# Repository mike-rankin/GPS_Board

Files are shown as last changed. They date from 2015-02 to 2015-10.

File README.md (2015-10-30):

On a Windows 7 machine place the contents on libraries.zip into a temp file on your computer.
Install Arduino 1.0.6

Place the TinyGPS library in your Arduino/libraries folder. On my PC its  MyDocuments/Arduino/libraries
Place the PinChangeInt library in your Arduino/libraries folder. On my PC its  MyDocuments/Arduino/libraries

In the same place as where the GPS_Cube.ino sketch is, place data.h, EEPROMAnything.h, mySoftwareSerial.cpp and mySoftwareSerial.h all in the same foilder.

Plug in the GPS Board and hopefully the FTDI chip driver will auto install, a new com port will appear
Pick Tools,Board Arduino Pro or Pro Mini
Pick Tools, Processor, ATmega328 (3.3v, 8 Mhz)
Verify in the IDE by viewing in Tools, Port does indeed show the new com port

Then in the IDE open the GPS_Cube.ino file. If it compiles error free then you are good to upload the sketch.

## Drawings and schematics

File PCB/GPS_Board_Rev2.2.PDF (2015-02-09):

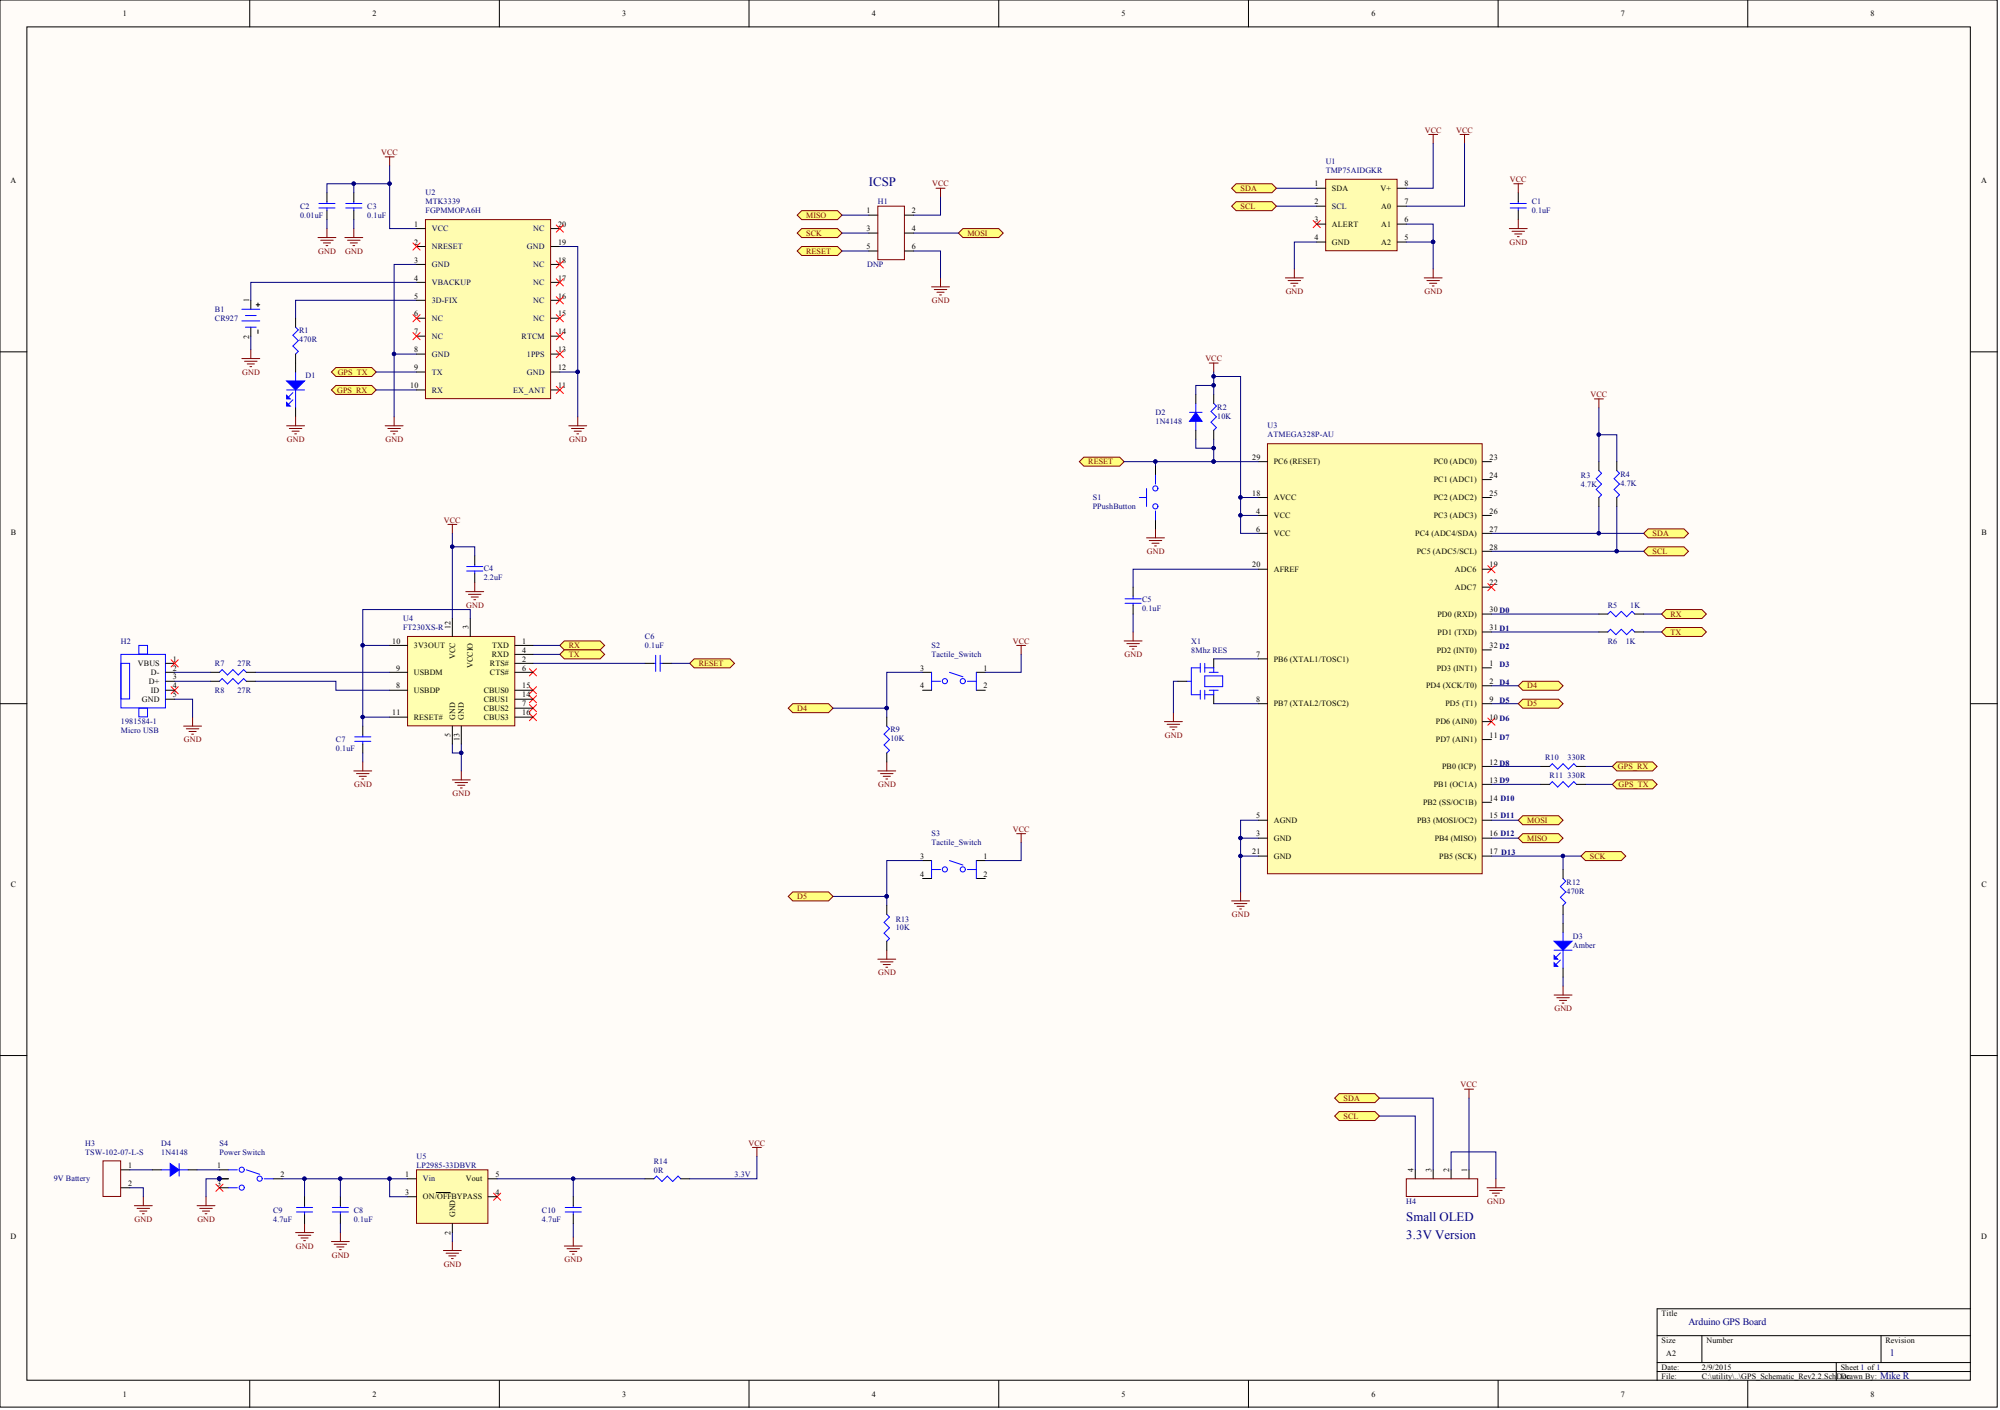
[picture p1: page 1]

VBACKUP 4

3D-FIX 5

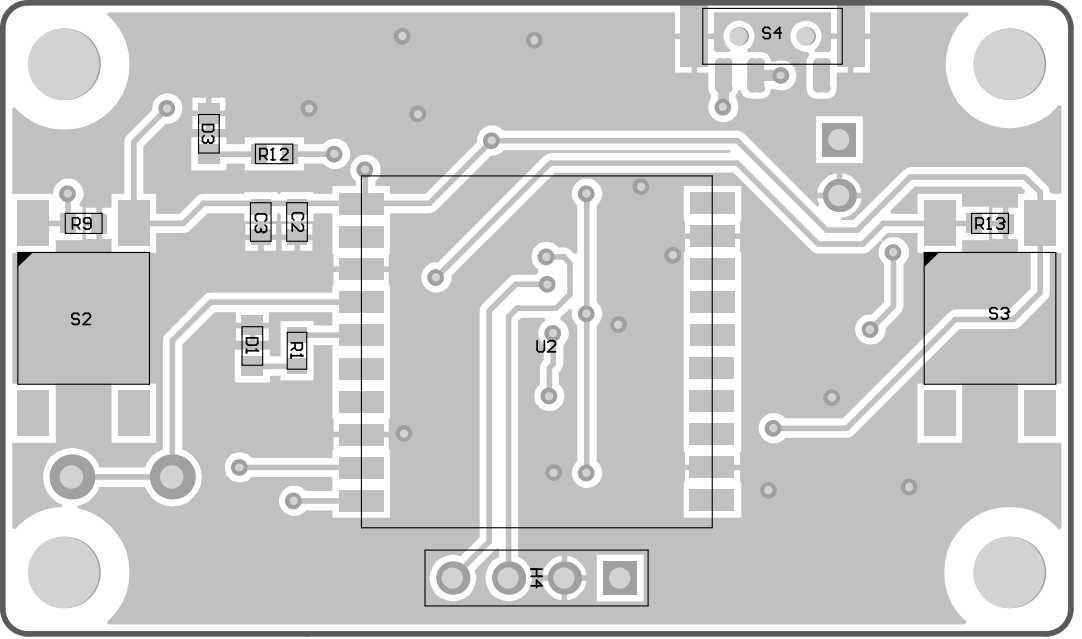
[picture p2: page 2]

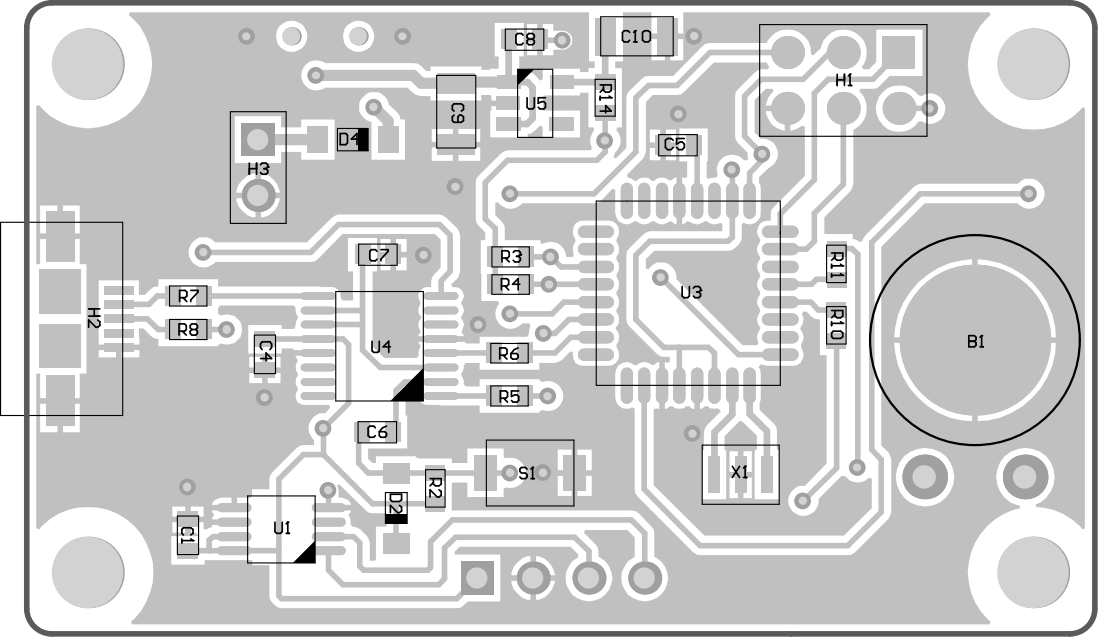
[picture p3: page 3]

Component list | Bill of Materials For Project [GPS_Board.PrjPCB] (No PCB Document Selected)
Source Data From: | GPS_Board.PrjPCB
Project: | GPS_Board.PrjPCB
Report Date: | 2/9/2015 | 10:23:58 AM
Print Date: | 09-Feb-15 | 10:24:01 AM

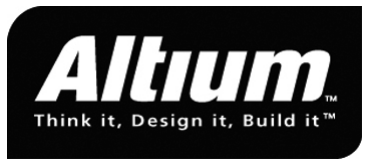
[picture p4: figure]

# | Designator | Quantity | Vendor | PartNumber | Description | Manufacturer | Comment

1 | B1 | 1 | DX.com | 202984 | Custom CR927 mount | | CR927
2 | C1, C3, C5, C6, C8 | 5 | | | CAP CER 0.1uF, 0603
3 | C2 | 1 | | | CAP CER 0.01uF, 0603 | | 0.01uF
4 | C4 | 1 | | | 2.2uF, 0602 | | 2.2uF
5 | C7 | 1 | | | CAP CER 0.1uF, 0603 | | 0.1uF
6 | C9, C10 | 2 | | | CAP CER 4.7uF, 1206 | | CAP_1206
7 | D1 | 1 | | | LED_0603 | | Green LED
8 | D2, D4 | 2 | Digikey | 1N4148W-TP | DIODE SWITCH 100V 0.15A SOD123 | Micro Commercial | 1N4148
9 | D3 | 1 | | Amber | LED_0603 | | LED_0603
10 | H1 | 1 | | DNP | CONN HEADER 3X2POS .100" PADS | | DNP
11 | H2 | 1 | Digi-Key | 1981584-1 | CONN RCPT MICRO USB TYPE AB | TE Connectivity | Micro USB
12 | H3 | 1 | | | CONN HEADER 2POS .100" SGL GOLD | Samtec | TSW-102-07-L-S
13 | H4 | 1 | | | CONN HEADER 4POS .100" SGL GOLD | Samtec | TSW-104-07-L-S
14 | R1, R12 | 2 | | | RES 0603 | | 470R
15 | R2, R9, R13 | 3 | | | RES 0603 | | 10K
16 | R3, R4 | 2 | | | RES 0603 | | 4.7K
17 | R5, R6 | 2 | | | RES 0603 | | 1K
18 | R7, R8 | 2 | | | RES 0603 | | 27R
19 | R10, R11 | 2 | | | RES 0603 | | 330R
20 | R14 | 1 | | | RES 0603 | | 0R
21 | S1 | 1 | | 122514 | DX_SWITCH TACTILE | | PPushButton
22 | S2, S3 | 2 | Digikey | FSM6JSMA | SWITCH TACTILE SPST-NO 0.05A 12V | TE Connectivity | Tactile_Sw itch
23 | S4 | 1 | DX.com | 122531 | DX_SWITCH SLIDE SPDT R/A
24 | U1 | 1 | Digikey | TMP75AIDGKR | IC DGTL TEMP SENSOR 2WIRE 8-MSOP | Maxim | TMP75AIDGKR
25 | U2 | 1 | | FGPMMOPA6H | GPS Chip - FGPMMOPA6H | Global Top | MTK3339
26 | U3 | 1 | Digikey | ATMEGA328P-AU | MCU AVR 32K FLASH 32TQFP | Atmel | ATMEGA328P-AU
27 | U4 | 1 | Digikey | FT230XS-R | IC USB SERIAL BASIC UART 16SSOP | FTDI | FT230XS-R
28 | U5 | 1 | Digikey | LP2985-33DBVR | IC REG LDO 3.3V .15A SOT23-5 | Texas Instruments | LP2985-33DBVR
29 | X1 | 1 | Digikey | CSTCE8M00G55-R0 | CER RESONATOR 8.0MHZ SMD | Murata
Approved | Notes

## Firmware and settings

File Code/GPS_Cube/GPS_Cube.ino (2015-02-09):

//Modified print_coord(); to prevent locking up in certain countries

//==========================================================//
//                                                          //
//    GPS Toy By KaR]V[aN, http://karman.homelinux.net      //
//    Thanks to the Arduino comunity for providing code,    //
//    libraries and platforms. Also many thanks to Nitz,    //
//    whose coding skills helped so much.                   //
//                                                          //
//==========================================================//

/* 
 * This is a simple GPS Toy/'on board computer' that shows GPS
 * data in a tiny 128x64 OLED display (I2C driven, 0.96").
 * Because being I2C display the frame rate is very slow 
 * but saves pins for future use.
 */
 
#include <EEPROM.h>
#include "EEPROMAnything.h"
#include "mySoftwareSerial.h" 
#include <TinyGPS.h>
#include <Wire.h>
#include <avr/pgmspace.h>

// So, why use a custom software serial? This addresses a problem sharing 
// interrupts between pinchangeint and software serial, by disabling the 
// unsued ports on both of them. Meanwhile pinchangeint allows easy disabling,
// newsoftwareserial doesn't, so have to comment code. More info:
// http://code.google.com/p/arduino-pinchangeint/issues/detail?id=7

//---------------FONT + GRAPHIC-----------------------------//
#include "data.h"
//==========================================================//

// OLED I2C bus address
#define OLED_address  0x3c

// Setup the GPS MT3339 receiver
#define PMTK_SET_NMEA_OUTPUT_RMCGGA "$PMTK314,0,1,0,1,0,0,0,0,0,0,0,0,0,0,0,0,0,0,0*28\r\n" // turn on GPRMC and GPGGA —– TinyGPS only uses these two, all others can be turned off
#define PMTK_SET_NMEA_UPDATE_1HZ "$PMTK220,1000*1F\r\n" // Every 1000ms (1Hz)
#define PMTK_SET_NMEA_UPDATE_2HZ "$PMTK220,500*2B\r\n" // Every 500ms (2Hz)
#define PMTK_SET_NMEA_BAUDRATE "$PMTK251,4800*14\r\n" // Baudrate to 4800
#define PMTK_API_SET_SBAS_ENABLED "$PMTK313,1*2E"   // Enable SBAS sattelite for fast fix
#define PMTK_API_SET_SBAS_Mode "$PMTK319,1*24"      // Integrity mode

// I'll attach interrupt to digital pins 4 and 5, both 
// on port D. Both ports B and C are to be disabled:
#define NO_PORTB_PINCHANGES // to indicate that port b will not be used for pin change interrupts
#define NO_PORTC_PINCHANGES // to indicate that port c will not be used for pin change interrupts
#include <PinChangeInt.h>

TinyGPS gps;
SoftwareSerial nss(9, 8);
static bool feedgps();
const int buttonA = 4;
const int buttonB = 5;
unsigned int buttonStateB = 0;      
unsigned int buttonStateA = 0;       
unsigned int mode=0;
bool course_degree = false;
bool control_blink = false;
bool control_clock = false;
bool interrupt = false;
bool doing_menu = false;
float SAVED_LAT = 0.0, SAVED_LON = 0.0, LAST_LAT = 0.0, LAST_LON = 0.0;
unsigned int TZ = 2;
unsigned long int tripDistance = 0;
static const byte settings_version = B10000011;
bool fix_first = 1;
float last_course = 0.0;
int TMP75_Address = 0x49;
float miniTimer = millis();
bool debug = 0; // turns on GPS data over USB serial



//---------------Saved Data Map-----------------------------//
// Bytes  Size  Purpose
// ····························································
// 0      1     Settings Version
// 1-4    4     Saved Latitude
// 5-8    4     Saved Longitude
// 9-10   2     Saved Mode
// 11     1     Saved Course preference (Degrees - Cardinal)
// 12     1     Saved Clock prefence (12h - 24h)
// 13-14  2     Saved Time Zone
// 15-18  4     Saved trip distance
//==========================================================//


void setup()
{
  // Load previous Settings
  byte read_settings_version;
  EEPROM_readAnything(0, read_settings_version);
 
  if(settings_version == read_settings_version) // If version matchs, load vars from EEPROM
  {  
    EEPROM_readAnything(1, SAVED_LAT);
    EEPROM_readAnything(5, SAVED_LON);
    EEPROM_readAnything(9, mode);
    EEPROM_readAnything(11, course_degree);
    EEPROM_readAnything(12, control_clock);
    EEPROM_readAnything(13, TZ);
    EEPROM_readAnything(15, tripDistance);
  }
  else                                          // If not, initialize with defaults
  {
    EEPROM_writeAnything(0, settings_version);
    EEPROM_writeAnything(1, SAVED_LAT);
    EEPROM_writeAnything(5, SAVED_LON);
    EEPROM_writeAnything(9, mode);
    EEPROM_writeAnything(11, course_degree);
    EEPROM_writeAnything(12, control_clock);
    EEPROM_writeAnything(13, TZ);
    EEPROM_writeAnything(15, tripDistance);
  }
  
  // Buttons...
  pinMode(buttonA, INPUT);
  pinMode(buttonB, INPUT);    
  digitalWrite(buttonA, LOW);
  digitalWrite(buttonB, LOW);
  
  // Attach interrupts to both buttons on rising change
  PCintPort::attachInterrupt(buttonA, &interrupt_button, RISING); 
  PCintPort::attachInterrupt(buttonB, &interrupt_button, RISING); 
 
  // Initialize GPS receiver
  // nss.begin(4800); // Old GPS EM411
  // Init in 9600 just in case MT3339 lost its settings
  nss.begin(9600);
  while (!nss.available()){} // yeah I know, ugly way to empty buffer...
  nss.print(PMTK_SET_NMEA_BAUDRATE); // baudrate to 4800

  // .. then delay 10ms and re-initialize in 4800
  delay(10);  
  nss.begin(4800);   
  while (!nss.available()){} // ...
  nss.print(PMTK_SET_NMEA_OUTPUT_RMCGGA); // $GPxxx Messages
  nss.print(PMTK_SET_NMEA_UPDATE_1HZ); // messages 2 times a second
  nss.print(PMTK_API_SET_SBAS_ENABLED); // enable SBAS fixing
  nss.print(PMTK_API_SET_SBAS_Mode); // integrity mode for SBAS
 
  // Initialize I2C and OLED Display
  Wire.begin();
  init_OLED();
 
  // Initialize TMP75
  Wire.beginTransmission(TMP75_Address);       // Address the TMP75 sensor
  Wire.write(0x01);                       // Address the Configuration register 
  Wire.write(B01100000);                         // Set the temperature resolution 
  Wire.endTransmission();                      // Stop transmitting
  Wire.beginTransmission(TMP75_Address);       // Address the TMP75 sensor
  Wire.write(0x00);                          // Address the Temperature register 
  Wire.endTransmission();                      // Stop transmitting 

  reset_display();           // Clear logo and load saved mode
  nss.listen();
  if (debug)
    Serial.begin(115200);
}


//==========================================================//
void loop()
{  
  // Read Button state
  if (buttonStateA == HIGH || buttonStateB == HIGH)
  {
    doing_menu = true;                            // we are in button fuctions, ignore interrupt bool
    unsigned long button_delay = millis();
    
    while (millis() - button_delay < 50) 
    {
      if (buttonStateA == LOW) 
        buttonStateA = digitalRead(buttonA);
      if (buttonStateB == LOW) 
        buttonStateB = digitalRead(buttonB);
    }
      
    // Both buttons pushed
    if (buttonStateB == HIGH && buttonStateA == HIGH)
    {
      displayOff();
      setXY(0,0);
  
      for(int i=0;i<128*8;i++)     // show 128* 64 Logo
        SendChar(pgm_read_byte(logo+i));
    
      displayOn();
      sendStrXY("Carlos Sancho",7,2);
      sendStrXY("v1.1", 0, 12);
      delay(5000);
      clear_display();
      sendStrXY("Hardware Design by Mike Rankin",0,0);
      sendStrXY("Using TinyGPS by Mikal Hart",3,0);
      sendStrXY("http://karman.cc",6,0);
      delay(5000);
      reset_display();
    }
    
    // Menu/mode button
    else if(buttonStateA == HIGH && buttonStateB == LOW) 
    {
      // Change mode
      if (mode == 0) 
        mode = 1;
      
      else if (mode == 1) 
        mode = 2;
        
      else if (mode == 2)
        mode = 3;
        
      else if (mode == 3)
        mode = 0;
      
      EEPROM_writeAnything(9, mode); // Save mode
      reset_display();
    } 
    
    // Other button
    else if (buttonStateB == HIGH && buttonStateA == LOW) 
    {
      reset_buttons();
      
      // Change cardinal <-> degrees
      if (mode == 0) 
      {
        course_degree = !course_degree;
        EEPROM_writeAnything(11, course_degree);
        reset_display();
      }
      
      // Memorize current location after 3 seconds pushing button
      else if (mode == 1) 
      {
        displayOff();
        clear_display();
        sendStrXY("Memorizing in: ", 0, 0);
        printBigNumber('3', 3 ,6);
        displayOn();
        boolean exit = 0;
        unsigned long start = millis();
        while (digitalRead(buttonB) == HIGH && !exit)
        {          
          if (millis() - start > 3000) 
          {
            clear_display();
            exit = true;
            sendStrXY("Coordinates memorized:", 0, 0);
            saveActualLoc(gps);
            delay(2000);
          } 
          
          else if (millis() - start > 2000)
            printBigNumber('1', 3 ,6);
            
          else if (millis() - start > 1000)
            printBigNumber('2', 3 ,6);
        }
        reset_display();
      }
      
      // Reset trip 
      else if (mode == 2)
      {
        displayOff();
        clear_display();
        sendStrXY("Clearing in: ", 0, 0);
        printBigNumber('3', 3 ,6);
        displayOn();
        boolean exit = 0;
        unsigned long start = millis();
        while (digitalRead(buttonB) == HIGH && !exit)
        {          
          if (millis() - start > 3000) 
          {
            clear_display();
            exit = true;
            unsigned long age;
            float flat, flon;
            gps.f_get_position(&flat, &flon, &age);
            sendStrXY("Trip reseted", 0, 0);
            tripDistance = 0;
            LAST_LAT = flat;
            LAST_LON = flon;
            EEPROM_writeAnything(15, tripDistance);
            delay(2000);
          } 
          
          else if (millis() - start > 2000)
            printBigNumber('1', 3 ,6);
            
          else if (millis() - start > 1000)
            printBigNumber('2', 3 ,6);
        }
        reset_display();
      }
      
      // Change clock hour mode, 12h <-> 24h in short push (< 3 secs)
      // In long push (> 3 sec) enters in time zone setting mode
      else if (mode == 3)
      {
        reset_buttons();
        boolean exit = 0;
        boolean mode_timezone = false;
        unsigned long start = millis();
        while (digitalRead(buttonB) == HIGH && !exit)
        {
          if (millis() - start > 3000) 
          {
            exit = true;
            mode_timezone = true;
          }
        }
        
        if (mode_timezone)
        {
          displayOff();
          clear_display();
          sendStrXY("Select TimeZone:", 0, 0);
          sendStrXY("Menu to set", 7, 2);
          displayOn();
          reset_buttons();
          bool print_TZ = true;
          while(buttonStateA != HIGH)
          {
            
            if (buttonStateB == HIGH) 
            {
              // this loop avoids false contacts of defective switches and sparks
              while (digitalRead(buttonB) != LOW)
                delay(10); 
              
              buttonStateB = LOW;
              TZ++;
              print_TZ = true;
            }
            
            if (TZ == 13)
              TZ = -11;
            
            // Avoid to print always same value
            if (print_TZ) {
              print_timezone(TZ);
              print_TZ = false;
            }
            
            delay(10); // to not fall into an endless loop. 
          }
          EEPROM_writeAnything(13, TZ);
        }
        else 
        {
          control_clock = !control_clock;
          EEPROM_writeAnything(12, control_clock);
        }
        reset_display();
      }
    }
    reset_buttons();
    doing_menu = false;    // Reset both vars on buttons exit
    interrupt = false;
  }
  
  
  // Update display
  updateScreen(gps);  
     
  // update trip distance
  udpateTrip(gps);
}

// Change button state on interrupt
void interrupt_button (void)
{
  if (PCintPort::arduinoPin == buttonA)
    buttonStateA = HIGH;
  else if (PCintPort::arduinoPin == buttonB)
    buttonStateB = HIGH;
    
  interrupt = true;          // Stop printing on display, speeds up response.
}

// Resets button states
static void reset_buttons(void)
{
  buttonStateA = LOW;
  buttonStateB = LOW;
}

//==========================================================//
// Resets display depending on the actual mode.
static void reset_display(void)
{
  displayOff();
  clear_display();
  if (mode == 0)
  {
    printKmh_unit();
  }
  else if (mode == 1) 
  {
    //nothing here by now
  } 
  else if (mode == 2) 
  {
    sendStrXY("Trip sum:", 0, 3);
  }
  else if (mode == 3)
  {
  //  sendStrXY("Atomic GPS Watch",0,0);
  }  
  updateScreen(gps);
  displayOn();
}

//==========================================================//
// Updates screen depending on the actual mode.
static void updateScreen(TinyGPS &gps) 
{
  unsigned long age;
  float flat, flon;
  gps.f_get_position(&flat, &flon, &age);
  
  if (mode == 0)
  {
    print_date(gps);
    printAlt(gps.f_altitude(), 0, 0);
    printSpeed(gps.f_speed_kmph());
    printSats(gps.satellites(), 0, 10, age);
    printCourse(gps); 
  }  
  else if (mode == 1)
  { 
    print_coord(flat, TinyGPS::GPS_INVALID_F_ANGLE, 0, 0);
    print_coord(flon, TinyGPS::GPS_INVALID_F_ANGLE, 0, 9);
    sendDistanceBetwen(gps);
    printCourse(gps);
    print_coord(SAVED_LAT, TinyGPS::GPS_INVALID_F_ANGLE, 7, 0);
    print_coord(SAVED_LON, TinyGPS::GPS_INVALID_F_ANGLE, 7, 9);
  }
  else if (mode == 2)
  {
    printTrip();
    printTemp(7,0);
    printSats(gps.satellites(), 7, 10, age);
  }
  else if (mode == 3)
  {
    print_date(gps);
    printTemp(0,0);
    printSats(gps.satellites(), 0, 10, age);
  }
}



//==========================================================//
// Shows and saves actual coordinates
static void saveActualLoc(TinyGPS &gps)
{
  unsigned long age;
  float flat, flon;
 
  gps.f_get_position(&flat, &flon, &age);
  sendStrXY("Lat: ", 4, 0);
  sendStrXY("Lon: ", 5, 0);
  print_coord(flat, TinyGPS::GPS_INVALID_F_ANGLE, 4, 5);
  print_coord(flon, TinyGPS::GPS_INVALID_F_ANGLE, 5, 5);
  SAVED_LAT = flat;
  SAVED_LON = flon;
  EEPROM_writeAnything(1, SAVED_LAT);
  EEPROM_writeAnything(5, SAVED_LON);
}

//==========================================================//
// Prints display trip update
static void printTrip () {
 /* char sz[32];
  sprintf(sz, "RAW: %d", tripDistance);
  sendStrXY(sz, 7, 0);*/
  print_distance(tripDistance);
}

//==========================================================//
// Gets current location and if > 20, sums to trip global var.
static void udpateTrip (TinyGPS &gps) {
  unsigned long age;
  float flat, flon;
  int max_dist = 25;
 
  gps.f_get_position(&flat, &flon, &age);
  if (flat == TinyGPS::GPS_INVALID_F_ANGLE)
    return;
  else {
    
    int mySpeed = (int)gps.f_speed_kmph();
    
    if(mySpeed > 5) 
      max_dist = 20;
    if(mySpeed > 10) 
      max_dist = 15;
    if(mySpeed > 15) 
      max_dist = 5;
    
    if(fix_first) 
    {
      LAST_LAT = flat;
      LAST_LON = flon;
      fix_first = false;
      last_course = TinyGPS::course_to(flat, flon, LAST_LAT, LAST_LON);
    } 
    else 
    {
    
      // Distance in meters
      unsigned long int dist = (long int)TinyGPS::distance_between(flat, flon, LAST_LAT, LAST_LON);

      if (dist > max_dist)   
      {
        
        // Try some course correction, props to Nitz
        float actual_course = TinyGPS::course_to(flat, flon, LAST_LAT, LAST_LON);
        float new_course = last_course - actual_course;
        new_course -= new_course / 2;
       
        tripDistance += dist * fabs((float)cos(new_course));
        
        last_course = actual_course;
        LAST_LAT = flat;
        LAST_LON = flon;
        EEPROM_writeAnything(15, tripDistance);
      }
    }   
  }
}

//==========================================================//
// Prints actual course or course to a point (distance mode) 
// in cardinal or dregree mode.
static void printCourse(TinyGPS &gps) 
{
  unsigned long age;
  float flat, flon;
  gps.f_get_position(&flat, &flon, &age);
  
  if (flat == TinyGPS::GPS_INVALID_F_ANGLE) 
    sendStrXY("C:N/A", 2, 10);
  else
  {
    char sz[32];
    if(course_degree)       // Print course in degrees mode
    {
      char sy[10];
      
      if (mode == 0)
        dtostrf(gps.f_course(),3,0,sy);
      else if (mode == 1)
        dtostrf(TinyGPS::course_to(flat, flon, SAVED_LAT, SAVED_LON),3,0,sy);
        
      sprintf(sz, "C:%s", sy);
      
      setXY(2, 15);
      for(int i=0;i<8;i++)     // print degree simbol
        SendChar(pgm_read_byte(myDregree+i));
    }    
    else                // Print course in cardinal mode
    {
      char tmp[3];
     
      if (mode == 0)
        sprintf(tmp, "%s", TinyGPS::cardinal(gps.f_course()));
      else if (mode == 1)
        sprintf(tmp, "%s", TinyGPS::cardinal(TinyGPS::course_to(flat, flon, SAVED_LAT, SAVED_LON)));
        
      int lon = strlen(tmp);
 
      sprintf(sz, "C:% 3s", tmp);
    }
      
    sendStrXY(sz, 2, 10);
  }
}


//==========================================================//
// Prints distance between two points given by actual and saved coordinates.
// To do so, function gets the two mayor magnitudes and prints them.
static void sendDistanceBetwen(TinyGPS &gps) 
{
  unsigned long age;
  float flat, flon;
  //char unit[10] = "m ";
 // char sz[32];
 // char next_unit[2];
 
  gps.f_get_position(&flat, &flon, &age);
  if (flat == TinyGPS::GPS_INVALID_F_ANGLE)
  {
    //sendDistance("000", " m");
    sendSpeed("000");
    sendStrXY("m ", 5, 9);
    sendStrXY("000*", 5, 12);
  }
  else {
    // Distance in meters
    unsigned long int dist = (long int)TinyGPS::distance_between(flat, flon, SAVED_LAT, SAVED_LON);
    print_distance(dist);
 
  }
}

//==========================================================//
// Prints distance.
static void print_distance (unsigned long int dist)
{
   char unit[10] = "m ";
   char sz[32];
   char next_unit[2];
   char tmp[32];
   unsigned long int little_ones;
   unsigned long int big_ones;
   
   if (dist >= 1000000000) 
    {
      little_ones = (dist % 1000000000) / 1000000;
      big_ones = (dist - (little_ones * 1000000)) / 1000000000;
      sprintf(next_unit, "%s", "M");
      sprintf(unit, "%s", "Gm");
    }
    else if (dist >= 1000000) 
    {
      little_ones = (dist % 1000000) / 1000;
      big_ones = (dist - (little_ones * 1000)) / 1000000;
      sprintf(next_unit, "%s", "K");
      sprintf(unit, "%s", "Mm");
    }
    else if (dist >= 1000) 
    {
      little_ones = dist % 1000;
      big_ones = ((dist - little_ones) / 1000);
      sprintf(next_unit, "%s", "m");
      sprintf(unit, "%s", "Km");
    }
    else
    {
        big_ones = dist;
        little_ones = 0;
        sprintf(next_unit, "%s", "*");
        sprintf(unit, "%s", "m ");
    }
      
    sprintf(sz, "%03d", big_ones);
      
    sprintf(tmp, "%03d", little_ones);
          
  //  sendDistance(sz, unit);
    sendSpeed(sz);
    sendStrXY(unit, 5, 9);

    sendStrXY(tmp, 5, 12);
    sendStrXY(next_unit, 5, 15);
}


//==========================================================//
// Prints current sattelites being used by GPS module.
static void printSats(int sats, int X, int Y, int age)
{
  if (sats == TinyGPS::GPS_INVALID_SATELLITES || age > 3000)
    sendStrXY("NO SIG", X, Y);
  else {
    char sz[7];
    (sats>9)?sprintf(sz, "%d SAT", sats):sprintf(sz, "0%d SAT", sats);
    sendStrXY(sz, X, Y);
  }
}


//==========================================================//
// Prints altitude adjusting it to display representation.
static void printAlt(float altitud, int X, int Y)
{
  if (altitud == TinyGPS::GPS_INVALID_F_ALTITUDE)
    sendStrXY("00000 m", X, Y);
  else {
    char sz[32];
    int alt = (int)altitud;
    
    if (alt<0)
      sprintf(sz, "-%04d m", abs(alt));
    else
      sprintf(sz, "%05d m", alt);
      
    sendStrXY(sz, X, Y);
  }
}


//==========================================================//
// Prints Speed and it's first decimal adjusting 0 in the left.
static void printSpeed(float val)
{
  if(val == TinyGPS::GPS_INVALID_F_SPEED)
  {
      sendSpeed("000");
      sendStrXY(".0",5,14);
  }
  else {
    char sx[5];
    char sy[5];
    char sz[5];
    int num = (int)val;
    float tmp = val - num;
    
    dtostrf(tmp,3,1,sy);
    sprintf(sx, ".%c", sy[2]);
    sprintf(sz, "%03d", num);
   
    sendSpeed(sz);
    sendStrXY(sx,5,14);
  }
}

//Possibly Locking up Board
/*
//==========================================================//
// Prints a floating coordinate yanking last two decimals for display
// fitting.
static void print_coord(float val, float invalid, int X, int Y)
{
  char sz[] = "*******";
  if (val == invalid)
  {
    sendStrXY(sz,X,Y);
  }
  else
  {
    dtostrf(val,6,4,sz);
    sendStrXY(sz,X,Y);
  }
}
*/


//NEW
static int print_coord(float val, float invalid, int X, int Y)
{
  char sz[20]; //extra headroom since dtostrf size is unclear
  char display[8];
  memset(sz,0,sizeof(sz));
  memset(display,0,sizeof(display));

  if (val == invalid)
  {
    memset(display,'*',sizeof(display)-1);
    sendStrXY(display,X,Y);
  }
  else
  {
    dtostrf(val,6,4,sz);  
    //strncpy does not auto null terminate string 
    //so memset to zero required
    strncpy(display, sz, sizeof(display)-1); 
    sendStrXY(display,X,Y);
  }
  return strlen(display);
}
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

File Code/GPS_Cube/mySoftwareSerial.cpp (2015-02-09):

/*
SoftwareSerial.cpp (formerly NewSoftSerial.cpp) - 
Multi-instance software serial library for Arduino/Wiring
-- Interrupt-driven receive and other improvements by ladyada
   (http://ladyada.net)
-- Tuning, circular buffer, derivation from class Print/Stream,
   multi-instance support, porting to 8MHz processors,
   various optimizations, PROGMEM delay tables, inverse logic and 
   direct port writing by Mikal Hart (http://www.arduiniana.org)
-- Pin change interrupt macros by Paul Stoffregen (http://www.pjrc.com)
-- 20MHz processor support by Garrett Mace (http://www.macetech.com)
-- ATmega1280/2560 support by Brett Hagman (http://www.roguerobotics.com/)

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
The latest version of this library can always be found at
http://arduiniana.org.
*/

// When set, _DEBUG co-opts pins 11 and 13 for debugging with an
// oscilloscope or logic analyzer.  Beware: it also slightly modifies
// the bit times, so don't rely on it too much at high baud rates
#define _DEBUG 0
#define _DEBUG_PIN1 11
#define _DEBUG_PIN2 13
// 
// Includes
// 
#include <avr/interrupt.h>
#include <avr/pgmspace.h>
#include "Arduino.h"
#include "mySoftwareSerial.h"
//
// Lookup table
//
typedef struct _DELAY_TABLE
{
  long baud;
  unsigned short rx_delay_centering;
  unsigned short rx_delay_intrabit;
  unsigned short rx_delay_stopbit;
  unsigned short tx_delay;
} DELAY_TABLE;

#if F_CPU == 16000000

static const DELAY_TABLE PROGMEM table[] = 
{
  //  baud    rxcenter   rxintra    rxstop    tx
  { 115200,   1,         17,        17,       12,    },
  { 57600,    10,        37,        37,       33,    },
  { 38400,    25,        57,        57,       54,    },
  { 31250,    31,        70,        70,       68,    },
  { 28800,    34,        77,        77,       74,    },
  { 19200,    54,        117,       117,      114,   },
  { 14400,    74,        156,       156,      153,   },
  { 9600,     114,       236,       236,      233,   },
  { 4800,     233,       474,       474,      471,   },
  { 2400,     471,       950,       950,      947,   },
  { 1200,     947,       1902,      1902,     1899,  },
  { 300,      3804,      7617,      7617,     7614,  },
};

const int XMIT_START_ADJUSTMENT = 5;

#elif F_CPU == 8000000

static const DELAY_TABLE table[] PROGMEM = 
{
  //  baud    rxcenter    rxintra    rxstop  tx
  { 115200,   1,          5,         5,      3,      },
  { 57600,    1,          15,        15,     13,     },
  { 38400,    2,          25,        26,     23,     },
  { 31250,    7,          32,        33,     29,     },
  { 28800,    11,         35,        35,     32,     },
  { 19200,    20,         55,        55,     52,     },
  { 14400,    30,         75,        75,     72,     },
  { 9600,     50,         114,       114,    112,    },
  { 4800,     110,        233,       233,    230,    },
  { 2400,     229,        472,       472,    469,    },
  { 1200,     467,        948,       948,    945,    },
  { 300,      1895,       3805,      3805,   3802,   },
};

const int XMIT_START_ADJUSTMENT = 4;

#elif F_CPU == 20000000

// 20MHz support courtesy of the good people at macegr.com.
// Thanks, Garrett!

static const DELAY_TABLE PROGMEM table[] =
{
  //  baud    rxcenter    rxintra    rxstop  tx
  { 115200,   3,          21,        21,     18,     },
  { 57600,    20,         43,        43,     41,     },
  { 38400,    37,         73,        73,     70,     },
  { 31250,    45,         89,        89,     88,     },
  { 28800,    46,         98,        98,     95,     },
  { 19200,    71,         148,       148,    145,    },
  { 14400,    96,         197,       197,    194,    },
  { 9600,     146,        297,       297,    294,    },
  { 4800,     296,        595,       595,    592,    },
  { 2400,     592,        1189,      1189,   1186,   },
  { 1200,     1187,       2379,      2379,   2376,   },
  { 300,      4759,       9523,      9523,   9520,   },
};

const int XMIT_START_ADJUSTMENT = 6;

#else

#error This version of SoftwareSerial supports only 20, 16 and 8MHz processors

#endif

//
// Statics
//
SoftwareSerial *SoftwareSerial::active_object = 0;
char SoftwareSerial::_receive_buffer[_SS_MAX_RX_BUFF]; 
volatile uint8_t SoftwareSerial::_receive_buffer_tail = 0;
volatile uint8_t SoftwareSerial::_receive_buffer_head = 0;

//
// Debugging
//
// This function generates a brief pulse
// for debugging or measuring on an oscilloscope.
inline void DebugPulse(uint8_t pin, uint8_t count)
{
#if _DEBUG
  volatile uint8_t *pport = portOutputRegister(digitalPinToPort(pin));

  uint8_t val = *pport;
  while (count--)
  {
    *pport = val | digitalPinToBitMask(pin);
    *pport = val;
  }
#endif
}

//
// Private methods
//

/* static */ 
inline void SoftwareSerial::tunedDelay(uint16_t delay) { 
  uint8_t tmp=0;

  asm volatile("sbiw    %0, 0x01 \n\t"
    "ldi %1, 0xFF \n\t"
    "cpi %A0, 0xFF \n\t"
    "cpc %B0, %1 \n\t"
    "brne .-10 \n\t"
    : "+r" (delay), "+a" (tmp)
    : "0" (delay)
    );
}

// This function sets the current object as the "listening"
// one and returns true if it replaces another 
bool SoftwareSerial::listen()
{
  if (active_object != this)
  {
    _buffer_overflow = false;
    uint8_t oldSREG = SREG;
    cli();
    _receive_buffer_head = _receive_buffer_tail = 0;
    active_object = this;
    SREG = oldSREG;
    return true;
  }

  return false;
}

//
// The receive routine called by the interrupt handler
//
void SoftwareSerial::recv()
{
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
